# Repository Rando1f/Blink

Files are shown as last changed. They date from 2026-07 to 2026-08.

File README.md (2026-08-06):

# Blink
Blink is a desk tracking device that tracks the user's time spent on the desk per session, displaying different animations based on how long the user has been going for. It uses an ultrasonic sensor that measures the distance between the user and itself. If that distance was lower than 15 in., it tracks that the user has been sitting on his desk. If it is more than 15 in., it tracks that the user is away from his desk. 
the animation are vresions of the same mascot "rando1f"

### Used appication
multiple applications were used in the creatino of blink starting with 
<ul>
    <li>piskel: for animated pixelated gifs</li>
    <li>wokwi: for basic connection simulations</li>
    <li>Kicad: for PCB creation</li>
    <li>Auto desk fusion360: for the case creation</li>
    <li>VS code: for writing code and uploading it to the esp32   *must be paired with platformio extension</li>
</ul>

### How to use blink
Blink's code is meant to be flashed into an ESP32. This could be done through buying the PCP that was published in [production](production) here through the Gerber files, or through using a breadboard with the following wiring.This is going to be done through VS Code and PlatformIO or Arduino IDE, although I recommend using Visual Studio Code because it offers an easier time debugging or adding features if you want to.  
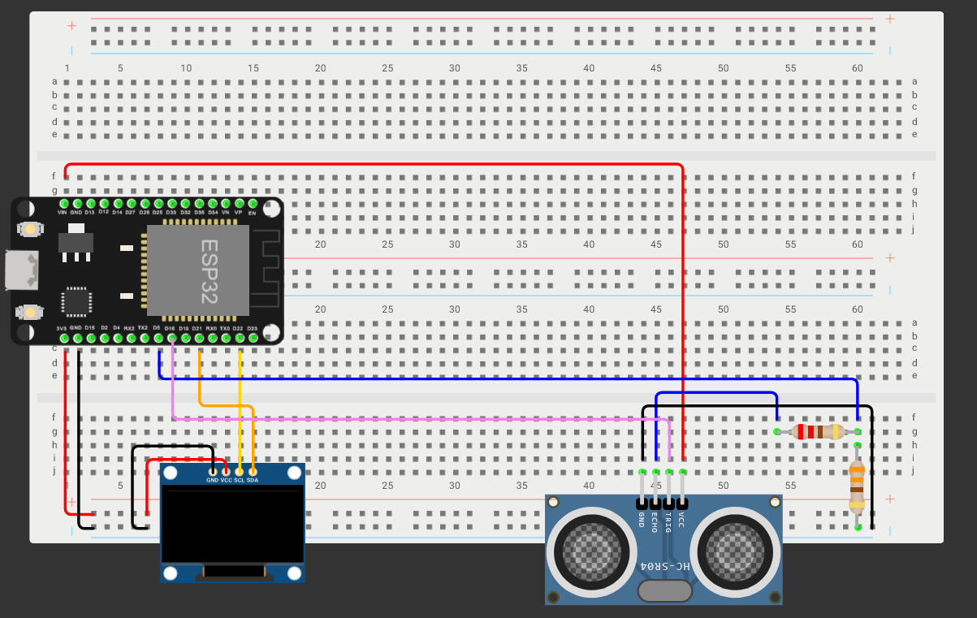
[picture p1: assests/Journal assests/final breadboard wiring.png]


blink is plugged into the users device through a micro-usb port that has clearance of about 0.5 mm in the case and is mounted on the bottom of your desk after you screw the lid with body of the case either through superglue or a doubled face tape since blink is fairly light.

### pcb 
BLINK PCB is built on the wiring showcased in the How to use BLINK section, where it links all of the components to an NGND with an OLED screen having a 3.3 V input with normal I2C protocol wiring, which is SDA: pin 21 and SCL: pin 22.
on the other hand HC-SR04 Has a VIN or a 5V input, and due to the ESP32's 3.3V capacity, a voltage divider of two resistors: Resistor 1 being 220, Resistor 2 being 330, To bring the voltage down towards the 3V, so it doesn't fry or break the ESP32 with default wiring of trig: pin 5 and echo: pin 18.  
the esp32 used in this project was esp32 devkit 30pin.
the dimensions of the pcb are: 74.93*85.55*20

<table>
<tr>
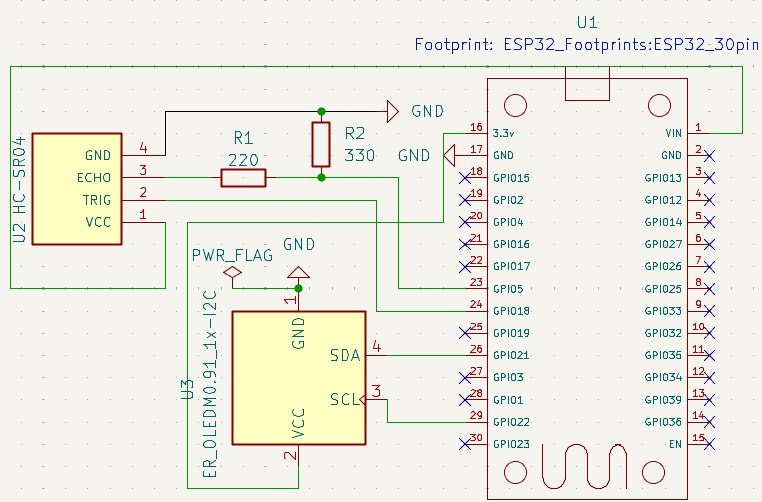
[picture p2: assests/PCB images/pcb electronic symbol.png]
    <td width="50%">
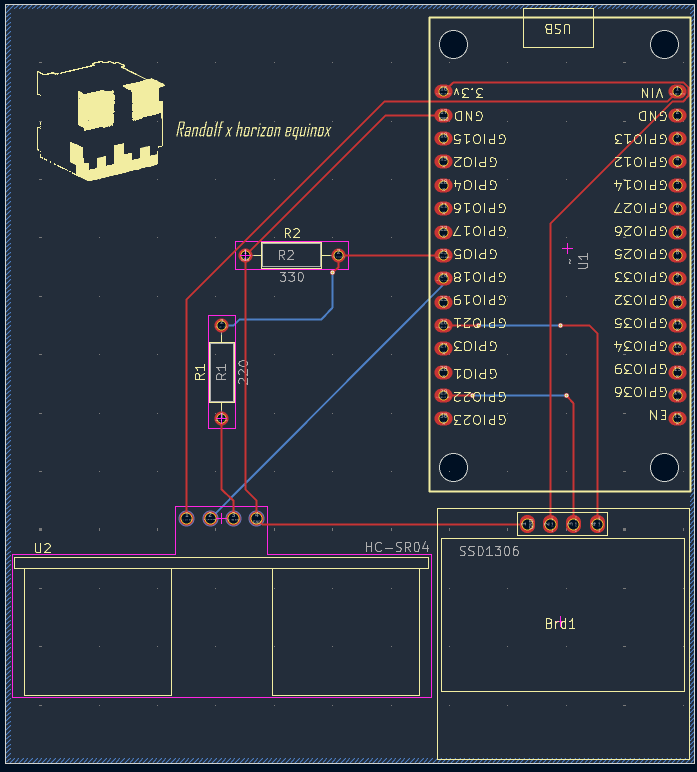
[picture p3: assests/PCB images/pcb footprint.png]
.</td>
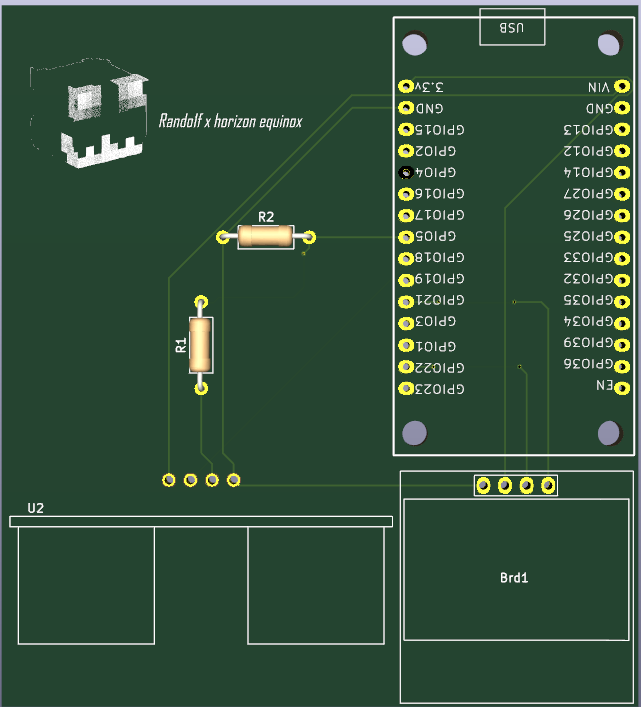
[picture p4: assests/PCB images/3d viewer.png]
    <td width="50%"> </td>
</tr>
</table>

### Case
the case was done with rough parts mesurments (beside the pcb with a 0.2mm tolarnce) and a casse thickness of 10mm.
the case features an ultrasonic sensor opening and an oled screen display cut extrusion where the oled screen would lie on a 90 degree angle with it being connecetd to the pcb trough jumper wires.
there are 4 studs on the 4 corners on the inside of the case to have a 3mm clearance below for all of the conections.
the case dimensions: 95.13mm *105.75mm *35 mm
the oled display dimensions: 20 mm* 27 mm
hc-sro4 diameter: 20
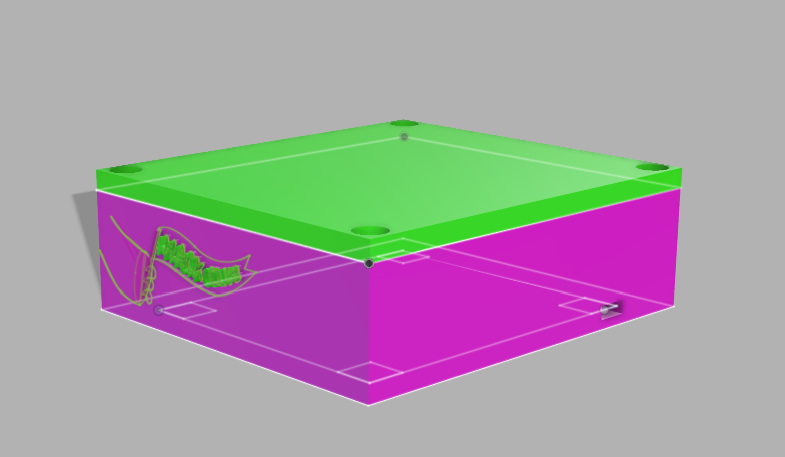
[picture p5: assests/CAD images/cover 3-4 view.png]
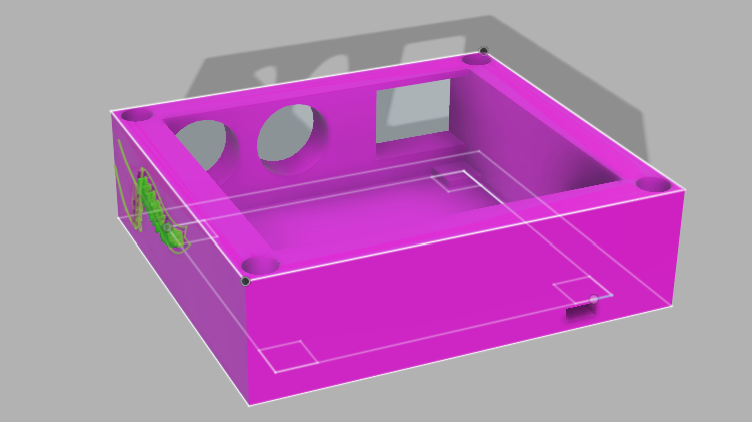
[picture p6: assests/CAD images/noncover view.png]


#### AI use

AI was only used for research purposes, and it wasn't used excessively. Rather, it was used as a resource-gathering tool so I could understand more of the project. The read.me is fully human-written, as well as the journal and the bill of materials.

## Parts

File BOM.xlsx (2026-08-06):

Item | amount | price | where to find
Oled 0.96" I2C display | 1 | 3.50$ | https://www.aliexpress.us/item/3256812545614079.html?curPageLogUid=8P5Jlx0MFX5l
HC-SR04 | 1 | 3$ | https://www.aliexpress.us/item/3256811352838466.html?curPageLogUid=2aQdqmYO1nzd
ESP32-devkit 30 pin | 1 | 5$ | https://www.aliexpress.us/item/3256809328863203.html?curPageLogUid=Ijy6ifc60dpK
jumper wiress M-F | 4+ | 1.6$ | https://www.aliexpress.us/item/3256807619227740.html?curPageLogUid=Cs66sieHiF3M

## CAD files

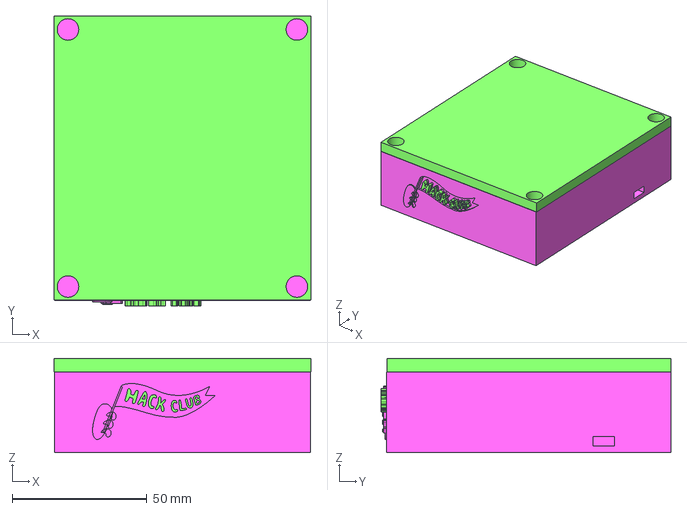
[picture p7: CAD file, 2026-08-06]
production/CAD/BLINK case.step
95.4 x 107.8 x 35.0 mm

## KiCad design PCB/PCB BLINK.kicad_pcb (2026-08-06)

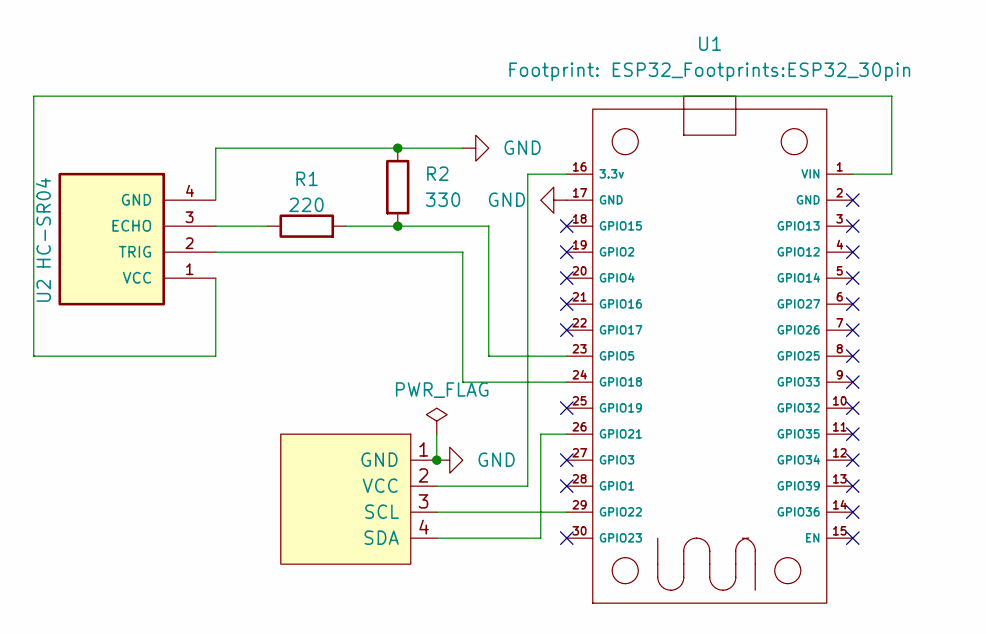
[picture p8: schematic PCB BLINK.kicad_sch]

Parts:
Brd1: SSD1306; 128x64OLED
R1: 220; R_Axial_DIN0207_L6.3mm_D2.5mm_P10.16mm_Horizontal
R2: 330; R_Axial_DIN0207_L6.3mm_D2.5mm_P10.16mm_Horizontal
U1: ESP32_30pin
U2: HC-SR04; XCVR_HC-SR04

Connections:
GND: Brd1.1 (GND), R2.1, U1.17 (GND), U2.4 (GND)
unnamed: Brd1.3 (SCL), U1.29 (GPIO22)
unnamed: Brd1.4 (SDA), U1.26 (GPIO21)
unnamed: Brd1.2 (VCC), U1.16 (3.3v)
unnamed: R1.2, R2.2, U1.23 (GPIO5)
unnamed: U1.24 (GPIO18), U2.2 (TRIG)
unnamed: U1.1 (VIN), U2.1 (VCC)
unnamed: R1.1, U2.3 (ECHO)

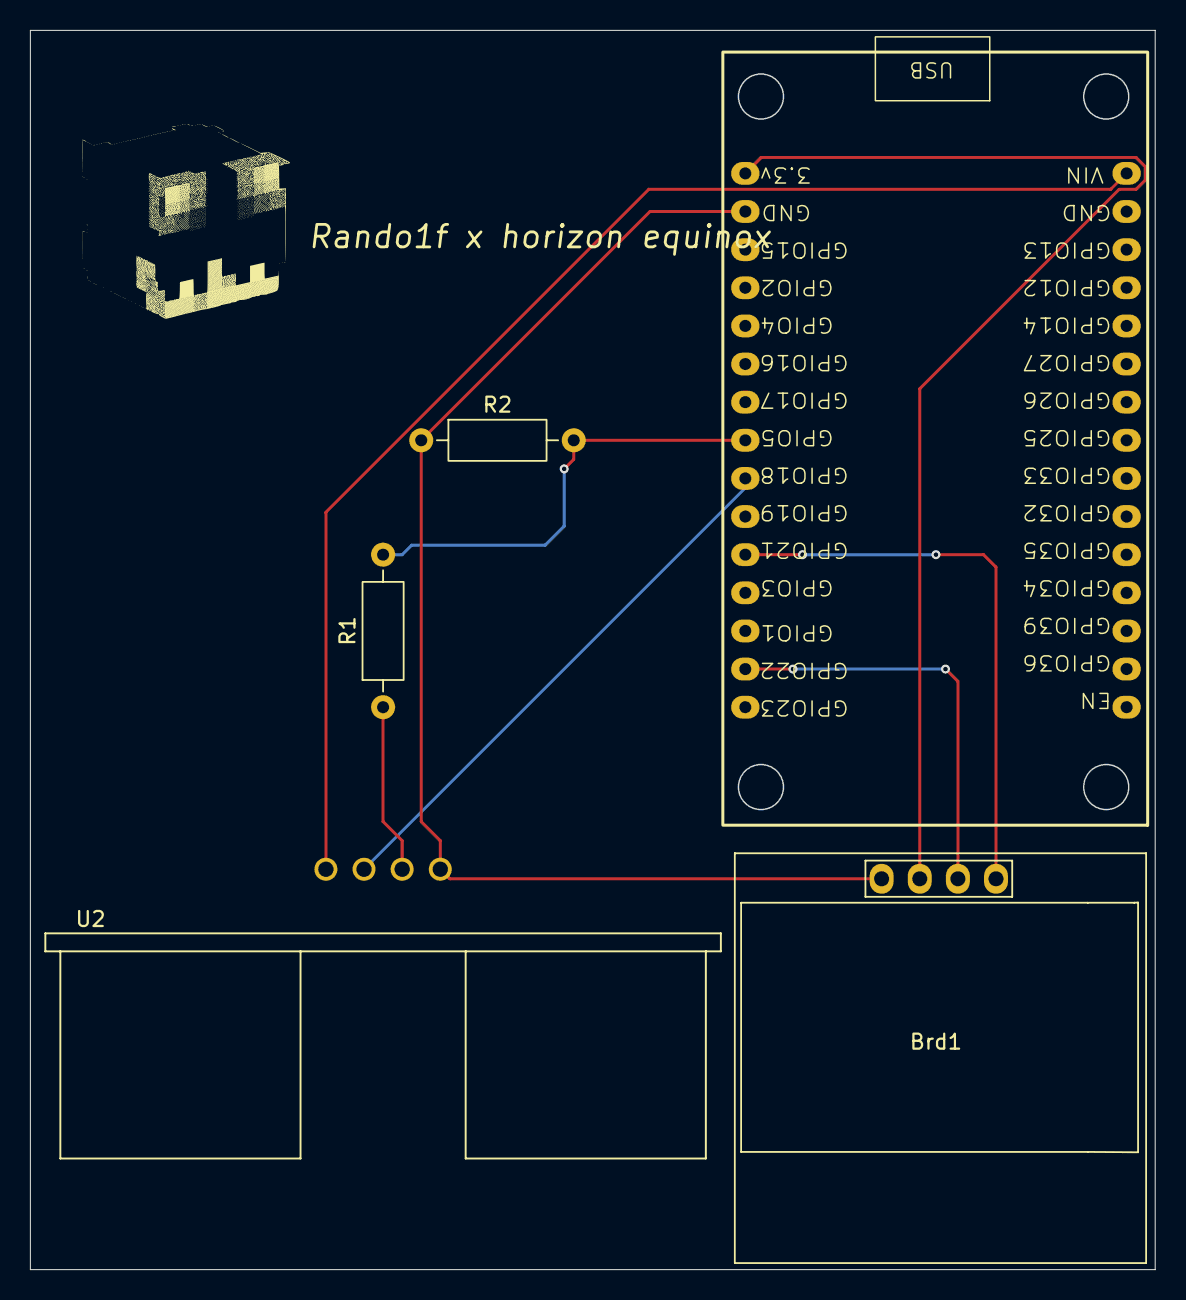
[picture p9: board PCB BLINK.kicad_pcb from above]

Board: 2 copper layers, 74.9 x 82.6 mm, 5 parts (0 on the bottom side), 8 nets.

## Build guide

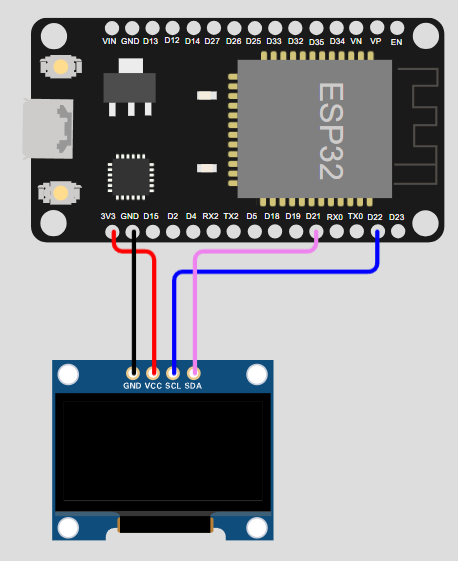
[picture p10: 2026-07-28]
assests/Journal assests/basic oled wiring.png

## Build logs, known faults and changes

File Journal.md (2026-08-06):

---
Title: BLINK
Author: Rando1f
Description: a desk companion montiring desk time with an artistic flair
Created_at: 27 / 7 / 2026
---
#### Total time spent: 45 hours
---
### Day 1 - getting started

Day one was primarily utilized through understanding the fundamentals of C and C++ Mainly void setup and void loop to understand how code is written and how I could write it in the future in order to use it properly, this was paired with acquiring knowledge about libraries as I begin understanding the GFX and SSD1306 libraries. 
downloading of them onto my platformio.ini file through using the lib_deps function.

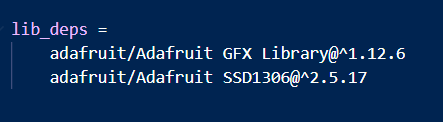
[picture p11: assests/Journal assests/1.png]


then an include function was used (#include) to include the aurdino framework, wire, GFX and SSD1306 to incorprete them in src/main where i then defined the dimeansions of the image which were a standered 128 by 64.

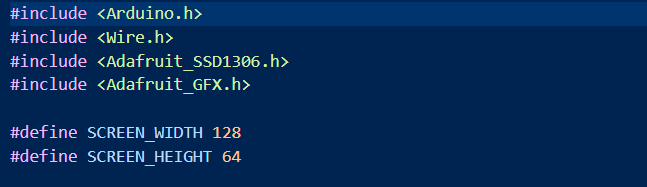
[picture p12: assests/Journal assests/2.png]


Where I used an LCD converter to convert my image into a C file, which contained monochromatic information about the image, which was then used to display it on the OLED 0.96-inch this was shown in [assests/image.c](assests\Image.c) showcasing an BLINKS mascot where I used.



the next step was fairly easy as it was th wiring using an esp32-WROOM-32 as the microcontroller and an OLED 0.96" LCD,I2C display. following the defult wiring for L2C.

GND: GND, 3V3: VCC, D21: SDA, D22: SCL

---
### Day 2 - animating the mascot
Day 2 primarily focused on creating an idle animation GIF file following the construction of the mascot as well as the wiring of the ultrasonic sensor. The process of creating a GIF was straightforward, although it was tedious due to the downsizing of the actual mascot image. The mascot had to be redrawn with a lower resolution of 128x64, resulting in way fewer colors existing as well as a lot of details getting lost.

which resulted in an unclear gif on the oled display due to the colors becoming monocramatic this was easily solved by enabling dithering.

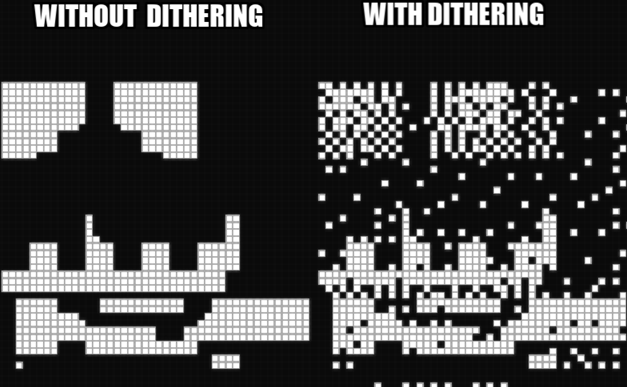
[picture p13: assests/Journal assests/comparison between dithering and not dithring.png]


this allows gradients to take place although it looks distorted at first glance it becomes very visable with small screens such as the one used in this project (I2C 0.96" oled display).
<table>
<tr>
<td width="40%">The idle animation featured a breathing animation. The breathing animation featured a blinking animation, quite frankly, due to the whole project being named Blink, as well as the character going up and down. This is a technique used by most pixel art artists to give the illusion of breathing. 
the gif was drawn and animated using piskel a free open-source pixel animation editor.
</td>
<td width="60%"> 
</td>
</tr>
</table>

<table>
<tr>
    <td width="40%">the wiring of the ultrasonic sensor consists of a voltage divider that turns the ECHO pin voltage outpot of 5v into a safe 3v voltage that the esp32 could handel, this was done through a combination of a 220Ω and 330Ω. 
    
where R1 is the 220Ω connecting 2 breadboard columns together and R2 (the one connect to the GND) is 330Ω and both of them being connected in the same colum creats something called resistor junction, this was done due to the ultrasonic sensor need for a 5v input which is given to it through the VIN pin but due to the esp32 input being 3.3v when the echo pin outputs its voltage it need to reach the esp32 as >= 3.3v which is ultimetly done through the resistor junction.

</td>
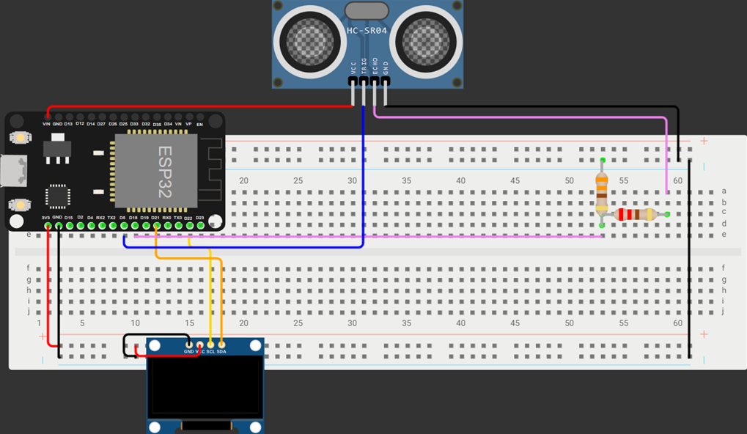
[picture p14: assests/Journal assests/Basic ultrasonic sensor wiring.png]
    <td width="60%"> </td>
</tr>
</table>

---
### day 3 - more gifs!!
Day 3 mainly consisted of desiging multiple gif animations these gif animations included 
<table>
<tr>
    <td width="60%">a confused animation while the mascot is still in "uniform".</td>
    <td width="40%"> </td>
</tr>

<tr>
    <td width="30%">a confused animation as to why he was waken up.</td>
    <td width="70%"> </td>
</tr>

<tr>
    <td width="60%">a surprised animation where the mascot is surprised (after a prolonged session of desk use without standing up)</td>
    <td width="40%"> </td>
</tr>

<tr>
    <td width="60%">a running animation when user has been working for sometime.</td>    
    <td width="40%"> </td>

</tr>
<tr>
    <td width="60%">a sleeping animation for when blink isn't active (the user is not near his desk for prolonged time)</td>
    <td width="40%"> </td>
</tr>

<tr>
    <td width="60%">a flaberrgasted animation when user spends alot of time using his desk generally
    <td width="40%"> </td> 
</tr>
</table>

these animation are going to be used conditionaly meaning that they are affected by there surronding this is done through the wiring of the ulrasonic sensor and general time.
*note that: every animation so far was drawn in piskel using an xp-pen but the same effects could be reached through using a mouse

---
### Day 4 - State machines
after drawing the GIF it came down to changinig the charcter states based on diffrent interactive conditions this was done by identifying what each gif was for. this was done on two rounds the written pseudocode and the graphed pseudocode.
the logic was done so that the idle state would be the starting state of any session and depending on the interactions it would follow the following logic tree:
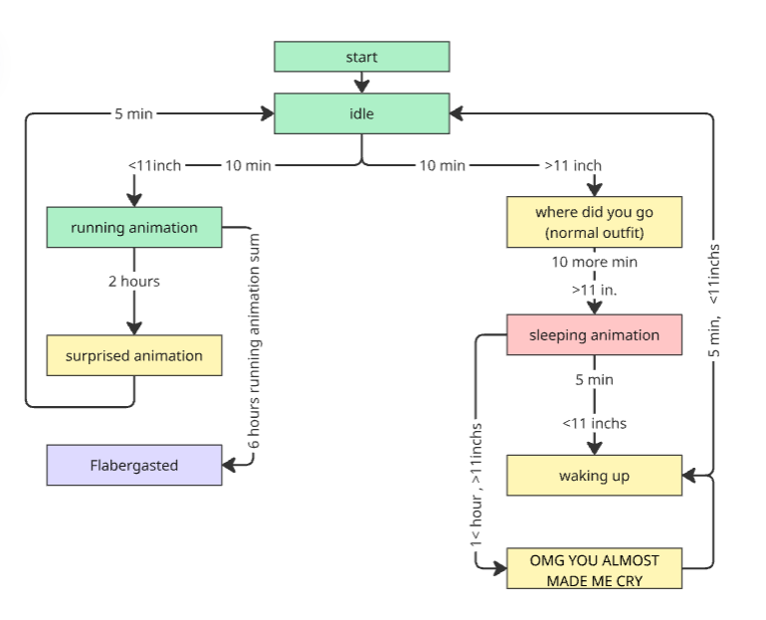
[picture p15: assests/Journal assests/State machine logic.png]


my first intution was using if conditions and for loops but i founded out that this wouldn't work due to the amount of if conditions and hierachel conditions it would be heavy on the esp32s' cpu and will take alot longer to code so i opted to using a state machine specifically a non-blocking state machine.

state machines are alot easier as it doesn't require me to keep calling on the frame individually as i used to do when testing the idle gif on day 2. 
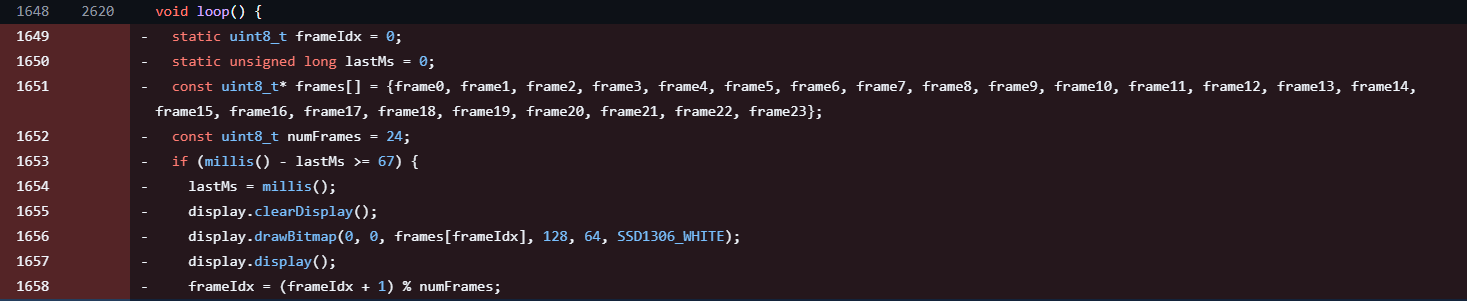
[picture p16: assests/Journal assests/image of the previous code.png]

*sorry for the image begin a commit history it was taken after the code was changed :3

this was done through assigning multiple frames to one array and recalling that array whenever needed whcih is faster and more effecient than calling the gif frame by frame.

### Day 5/6 - more state machine ?!
today consisted mostly of fixing some of the bugs found in the state machine such as the flabergasted state being unreachable or the surprised animation being impossiable to reach.
this was mostly due to incorrect logic as the time used to reach the surprised state was previously the current time or the entry time as the start time restarting the action meaning that it would endlessly run until flabergasted or it went to sleep/ the where did you go animation.
this was fixed in the new ittiration making the flabergasted animatino occuer after 6 hours of running (the continounity of the runnning isn't a must) for 10 min. before defulting to idle.

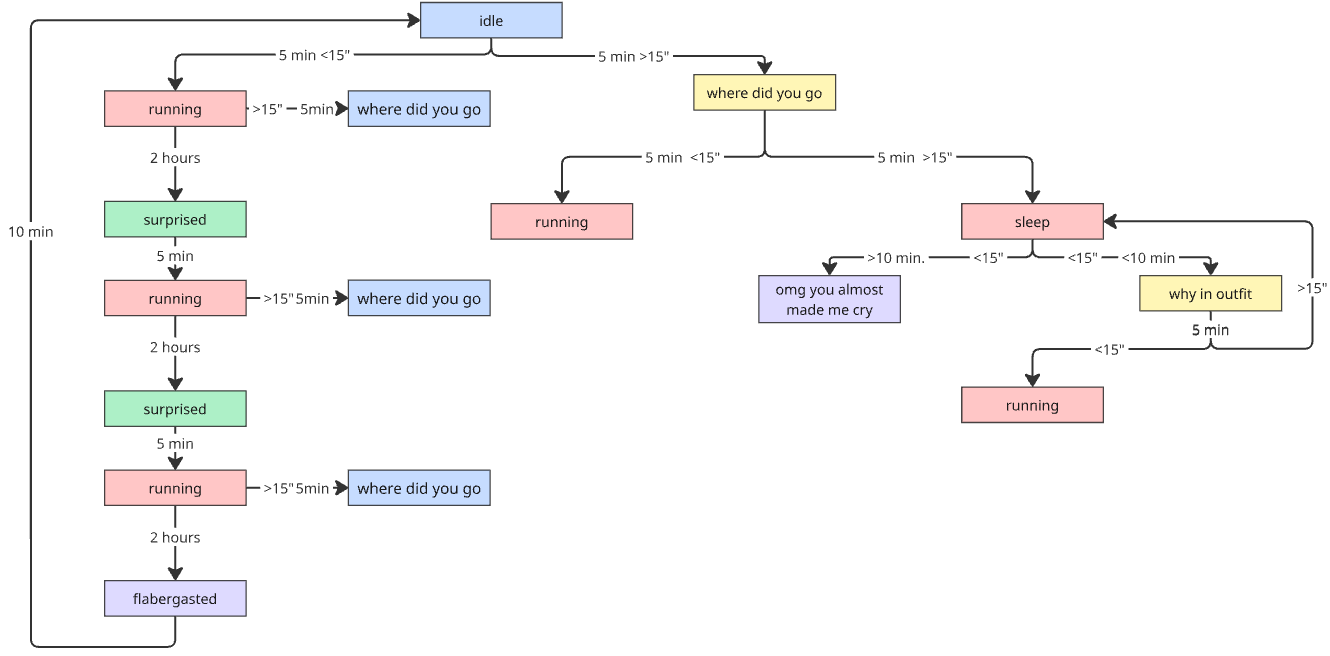
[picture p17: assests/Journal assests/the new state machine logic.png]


### DAY 7 - i can smell the end !! (pcb and CAD files)
today mostly consisted of me creating the pcb that was dieractly copied from the breadboard demo this was moderlty easy except for checking that everything was running correctly as some concepts were fairly new to me for example net gnd as i had to connect every electronic to the same GND which was done through using the GND symbol paired with a pwr_flag.



this was then used to create the footprint which was done through kicad as well, this was easir than the previous step due to the connection already being marked for me in which after a GND ground net was poured using B.CU on the PCB to allow for a net GND throguh the whole pcb.



with this being the final results (some step files were missing but they are used for cosmetic purposes only)



which this pcb is going to live in this casse designed based on rough mesurments of the hc-sro4 and oled 0.96" ssd1306 I2C screen 




---

<h1 style="text-align: center;"> ENJOY BLINK!! </h1>

*T-T finally

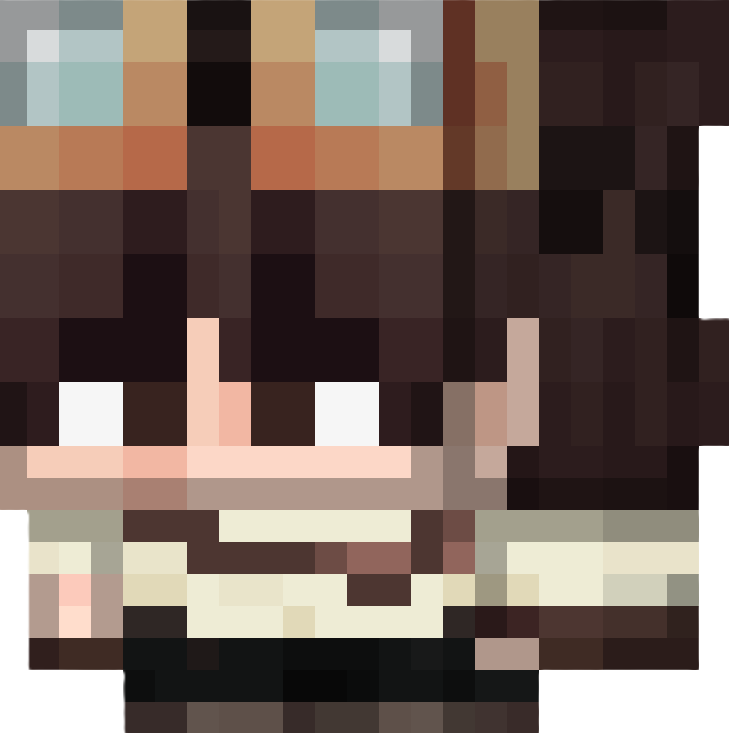
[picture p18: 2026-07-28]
assests/Journal assests/static mascot.png

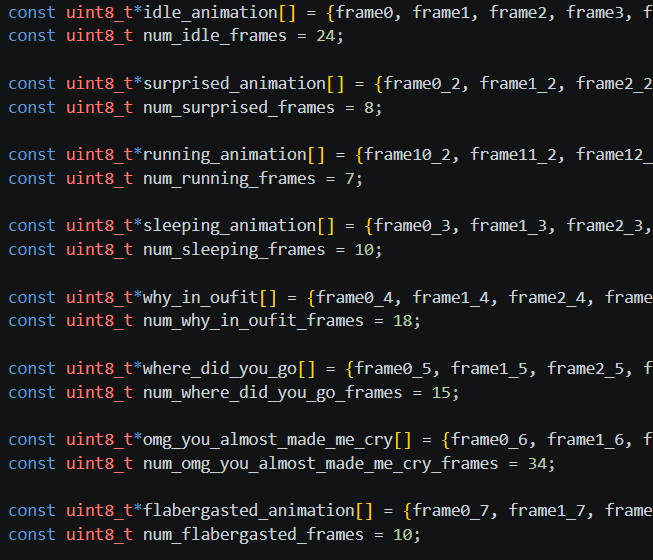
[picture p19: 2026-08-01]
assests/Journal assests/array code.png

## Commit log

2026-07-26 basic readme changes
    creating a readme line just to outline the frame of the project before actually doing anything
2026-07-28 journaling and oled demo code
    This commit mainly focuses on writing the demo display for the static mascot that I have currently. The next step is going to be to turn it into a GIF file and use if-conditions to identify what time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
2026-07-28 the first gif design
    This committee includes the first gif design for the ideal state of the mascot. Next steps are going to include showcasing the main feature, which is going to be linking the PIR with the ESP32 and OL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
2026-07-29 ultra sonic sensor update
    Writing the code for the ultrasonic sensor just so it can detect the distances and determine whether a distance is close or far in centimeters and inches. Although this is basic code that was publicl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
2026-07-31 adding the gifs bitmaps and delay fix
    using a millis() Over a delay function so only the ultrasonic sensor would detect every 0.5 seconds rather than the whole code running every 0.5 seconds
2026-08-03 PCB design
    [PCB BLINK.csv, PCB BLINK.kicad_pcb, PCB BLINK.kicad_sch]
2026-08-04 fixing the logic of the state machine
    I did a time counter feature although it is barely noticeable. It is not meant as a distraction or as a moving force for the user, more to track the time you actually spend on your device or on your desk. Also we changed the running animation background from a white background to a black background with a white mascot because it is pretty bad when it flashes white in your face.
2026-08-04 final ittirations
    fixing the sleep case
    and fixing the second going beyond 60
2026-08-04 pcb finilized
    [PCB BLINK.csv, PCB BLINK.kicad_pcb]
2026-08-06 case and pcb production
    [BLINK case.step, PCB BLINK.kicad_pcb, PCB BLINK.kicad_sch]
2026-08-06 fixed files hierarchy and naming
    [BLINK case.step, PCB BLINK.kicad_pcb, PCB BLINK.kicad_sch]
2026-08-06 writing the about me
    [BLINK case.step, BOM.xlsx]
